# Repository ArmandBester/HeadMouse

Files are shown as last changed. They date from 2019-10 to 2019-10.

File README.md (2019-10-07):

# HeadMouse

### An Arduino based human interface device (HID)
This device uses an [Arduino Micro](https://store.arduino.cc/arduino-micro) and will probably work with any ATmega32U4 based development board.  A [gyroscope sensor](https://www.amazon.com/Gy-521-MPU-6050-MPU6050-Sensors-Accelerometer/dp/B008BOPN40) is used as input.  The gyroscope input is smoothed and scaled by the arduino and using the [Mouse library](https://www.arduino.cc/reference/en/language/functions/usb/mouse/) is able to emulate mouse movements on a computer screen.  A pressure sensor XGZP6847 is used as input for click and scroll control.  

* Short blow = left click
* Longer blow = scroll down
* Short suck = right click
* Longer suck = scroll up

When the device is powered on via a USB cable, it automatically calibrates the ambient pressure.

The HeadMouse can be mounted on a gaming headset, this allows a good scaffold for the electronics as well as the microphone extension to which a mouthpiece is fixed to enable convenient pressure control.

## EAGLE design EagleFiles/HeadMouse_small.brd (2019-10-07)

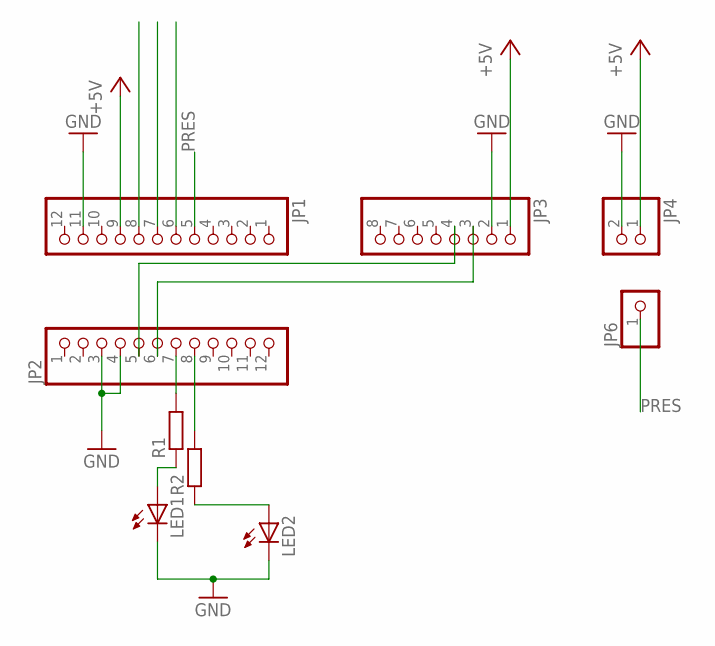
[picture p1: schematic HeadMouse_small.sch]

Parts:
JP1, JP2: PINHD-1X12; 1X12
JP3: PINHD-1X8BIG; 1X08-BIG
JP4: PINHD-1X2; 1X02
JP6: PINHD-1X1; 1X01
LED1, LED2: LED3MM
R1, R2: R-EU_0204/7; 0204/7

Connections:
+5V: JP1.9, JP3.1, JP4.1
GND: JP1.11, JP2.3, JP2.4, JP3.2, JP4.2, LED1.K (C), LED2.K (C)
unnamed: JP2.5, JP3.4
unnamed: JP2.8, R2.2
unnamed: LED1.A, R1.1
unnamed: LED2.A, R2.1
unnamed: JP2.7, R1.2
unnamed: JP2.6, JP3.3
PRES: JP1.5, JP6.1

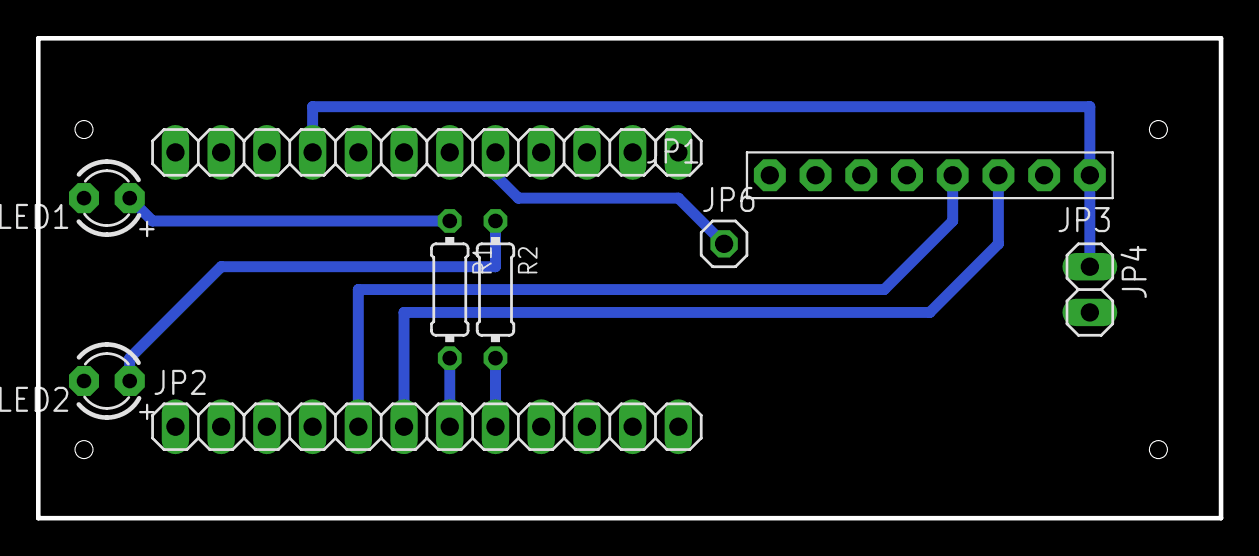
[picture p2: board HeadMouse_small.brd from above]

Board: 2 copper layers, 65.7 x 26.7 mm, 9 parts (0 on the bottom side), 9 nets.

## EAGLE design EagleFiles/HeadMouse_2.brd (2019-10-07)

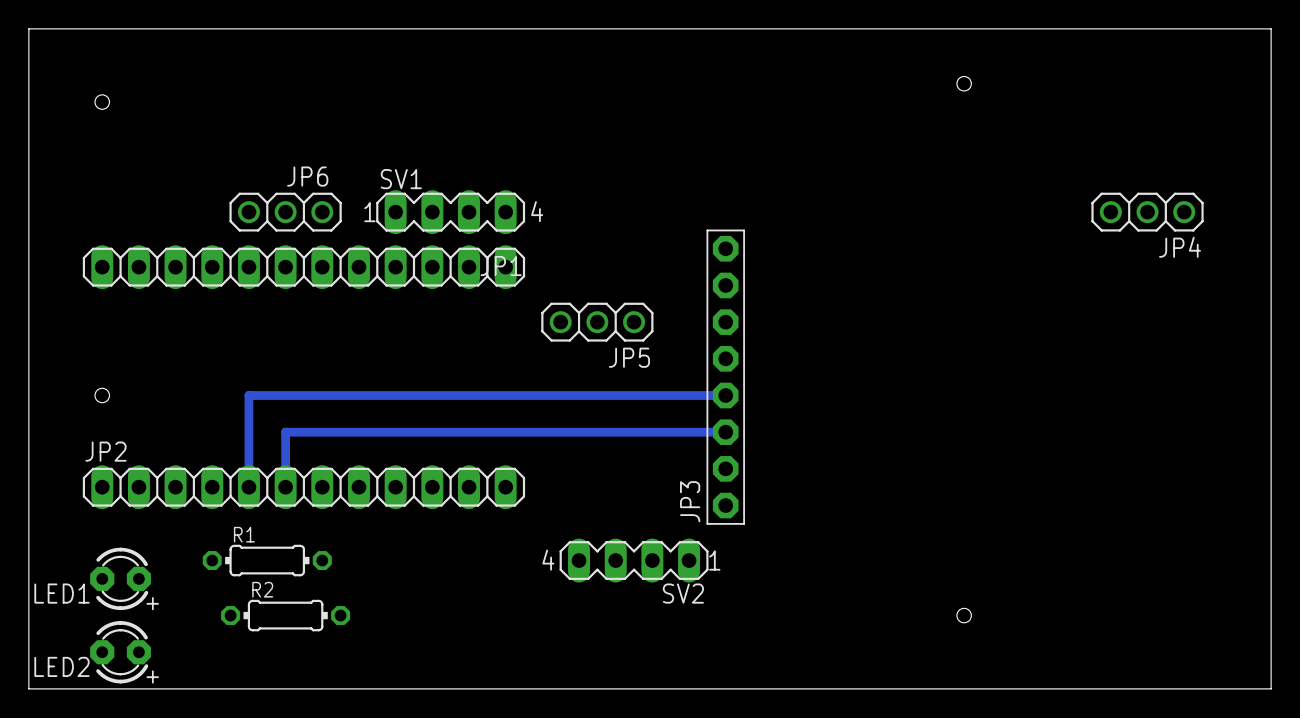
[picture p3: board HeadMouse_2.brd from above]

Board: 2 copper layers, 86.0 x 45.7 mm, 12 parts (0 on the bottom side), 20 nets.

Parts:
JP1, JP2: 1X12
JP3: 1X08-BIG
JP4, JP5, JP6: 1X03
LED1, LED2: LED3MM
R1, R2: 0204/7
SV1, SV2: MA04-1

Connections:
+5V: JP1.9, JP3.1, JP4.2
GND: JP1.11, JP2.3, JP2.4, JP3.2, JP4.3, LED1.K, LED2.K
unnamed: JP2.5, JP3.4
unnamed: JP2.8, R2.2
unnamed: LED1.A, R1.1
unnamed: LED2.A, R2.1
unnamed: JP2.7, R1.2
unnamed: JP2.6, JP3.3
unnamed: JP1.8, JP6.1
unnamed: JP1.7, JP6.2
unnamed: JP1.6, JP6.3
unnamed: JP1.4, SV1.1
unnamed: JP1.3, SV1.2
unnamed: JP1.2, SV1.3
unnamed: JP1.1, SV1.4
unnamed: JP2.9, SV2.4
unnamed: JP2.10, SV2.3
unnamed: JP2.11, SV2.2
unnamed: JP2.12, SV2.1
PRES: JP1.5, JP5.2

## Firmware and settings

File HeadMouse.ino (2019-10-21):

/*Use a gyroscope to emulate mouse movement and a presure
   sensor for clicking and scrolling using a mouth
   piece.
   Include some libraries
   MPU6050 and I2Cdev from https://github.com/jrowberg/i2cdevlib or forked at https://github.com/ArmandBester/i2cdevlib (probably best to stick with the original rather)
*/


#include <Mouse.h>
#include <I2Cdev.h>
#include <MPU6050.h>


//Define inttypes to the 6 axis values which will be obtained from the MPU6050
int16_t Ax, Ay, Az, Gx, Gy, Gz;
// From examples from the library
MPU6050 mpu;

//Define the values that will be sent to the Mouse
int mx;
int my;
//Define a scaler value to change the sensitivity of the mouse
int scaler = 100;



//Smoothing of mouse movement
const int nReadings = 5;
int xReadings[nReadings];
int yReadings[nReadings];
int xTot;
int yTot;
int xAvg;
int yAvg;
int readIndex;


//Timing control
//----> Mouse movement
unsigned long prevMouseMillis = 0;
const long mouseInterval = 5;  //10 is a safe value


//Pressure click and scroll
#define pPin A0
int p = 0;
int pTimerPos = 0;
int pTimerNeg = 0;
int pThresh = 50;
int clickTrigger = 300;
int scrollTrigger = 800;
int scrollDist = 10;


// Define pins for debuging mouse clicks, this is just LEDs
#define leftLedPin 4
#define rightLedPin 5

// On startup callebrate ambient pressure
int cPressure = 0;
int aPressure = 500;  //will update this value with cPressure


void setup() {

  Serial.begin(9600); //mostly for debugging
  pinMode(leftLedPin, OUTPUT);
  pinMode(rightLedPin, OUTPUT);

  pinMode(pPin, INPUT);

  // initialize the mpu
  mpu.initialize();
  if (!mpu.testConnection()) {
    while (1);
  }
  else {
    Serial.println("Could not find a valid MPU6050 sensor, check wiring!");
  }

  // Smoothing of mouse movement, initialize empty arrays
  for (int i = 0; i < nReadings; i++) {
    xReadings[i] = 0;
    yReadings[i] = 0;
  }

  //callibrate to ambient pressure

  for (int k = 0; k < 10; k++) {
    cPressure = cPressure + analogRead(pPin);
  }
  aPressure = cPressure/10;

  //end of setup

}



void loop() {

  // Mouse movement

  unsigned long currentMouseMillis = millis();

  if (currentMouseMillis - prevMouseMillis >= mouseInterval) {
    prevMouseMillis = currentMouseMillis;

    mpu.getMotion6(&Ax, &Ay, &Az, &Gx, &Gy, &Gz);
    mx = -(Gz - 200) / scaler; //adjust offsets for the gyro to cancel drift
    my = (Gy - 225) / scaler;

    //smoothing of mouse movement
    xTot = xTot - xReadings[readIndex];
    yTot = yTot - yReadings[readIndex];

    xReadings[readIndex] = mx;
    yReadings[readIndex] = my;

    xTot = xTot + xReadings[readIndex];
    yTot = yTot + yReadings[readIndex];

    readIndex = readIndex + 1;

    //reset readIndex if nReads are reached
    if (readIndex <= nReadings) {
      readIndex = 0;
    }

    xAvg = xTot / nReadings;
    yAvg = yTot / nReadings;


    Mouse.move(xAvg, yAvg);
    Serial.print(xAvg);
    Serial.print(" : ");
    Serial.println(yAvg);
  }


  // ENd of mouse movement
  //------------------------------------------------------------------------------//

  //Beginning of clicking and scrolling section

  //positive pressure controls
  if (analogRead(pPin) >= (aPressure + pThresh)){
    pTimerPos ++;
  }
  //left click
  if (analogRead(pPin) < (aPressure + pThresh) && pTimerPos >= clickTrigger && pTimerPos < scrollTrigger){
    Mouse.click();
    pTimerPos = 0;
  }
  //down scroll
  if (analogRead(pPin) < (aPressure + pThresh) && pTimerPos >= scrollTrigger){
    Mouse.move(0, 0, -scrollDist);
    pTimerPos = 0;
  }

  //negative pressure controls
  if (analogRead(pPin) <= (aPressure - pThresh)){
    pTimerNeg ++;
  }
  //right click
  if (analogRead(pPin) > (aPressure - pThresh) && pTimerNeg >= clickTrigger && pTimerNeg < scrollTrigger){
    Mouse.click(MOUSE_RIGHT);
    pTimerNeg = 0;
  }
  //up scroll
  if (analogRead(pPin) > (aPressure - pThresh) && pTimerNeg >= scrollTrigger){
    Mouse.move(0, 0, scrollDist);
    pTimerNeg = 0;
  }

  

  













}

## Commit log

2019-10-03 Started with pressure sensor
2019-10-05 Added callibrations routine for ambient pressure
2019-10-05 Added positive and negative pressure timers
2019-10-07 Added gerber and eagle cad files
    [HeadMouse_2.brd, HeadMouse_small.sch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]
2019-10-07 Fixed mistake in the Eagle folder
    [HeadMouse_small.brd]
2019-10-21 Changes to averaging and pressure threshold.
